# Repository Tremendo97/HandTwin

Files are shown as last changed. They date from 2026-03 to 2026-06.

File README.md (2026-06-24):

Este es el repositorio para el Trabajo Fin de Grado de Diego Hernández Pérez para el grado de de Desarrollo de aplicaciones 3D interactivas y videojuegos.

Resumen:

En el panorama actual se observa una gran explosión en la importancia de los gemelos digitales, siendo utilizados para una gran cantidad de actividades tanto dentro como fuera del ámbito industrial. A su vez, a lo largo de los años, se han ido desarrollando y perfeccionando pinzas y manos mecánicas que resultan muy útiles para actividades relacionadas con automatización, desarrollo de prótesis y otras aplicaciones.
En este proyecto de fin de grado se estudia el paradigma actual de las manos mecánicas, en conjunto con el concepto de gemelos digitales, para después proponer un diseño de una mano mecánica que recrea los movimientos de una mano humana real, controlada a través del uso de un Gemelo Digital desarrollado en Unreal 5.
Este proyecto pretende ser un primer paso hacia el control a distancia de manos mecánicas más complejas a través de la construcción de gemelos digitales que ofrezcan feedback real e instantáneo de su estado y posición.

This is the repository for the Bachelor's Thesis of Diego Hernández Pérez for the degree in Interactive 3D Application Development and Video Games.

Abstract:

In the current landscape, there is a significant surge in the importance of digital twins, which are being used for a wide range of applications both within and outside the industrial sector. At the same time, over the years, robotic grippers and mechanical hands have been continuously developed and refined, proving highly useful for tasks related to automation, prosthetics development, and other applications.
This Bachelor's Thesis studies the current state of mechanical hands in conjunction with the concept of digital twins. To then proposes the design of a mechanical hand capable of replicating the movements of a real human hand, controlled through the use of a Digital Twin developed in Unreal Engine 5.
This project aims to serve as a first step toward the remote control of more complex mechanical hands through the development of digital twins that provide real-time and accurate feedback on their state and position.

**Memoria**
[DiegoHernándezPérez-TFG.pdf](https://github.com/user-attachments/files/29307168/DiegoHernandezPerez-TFG.pdf)

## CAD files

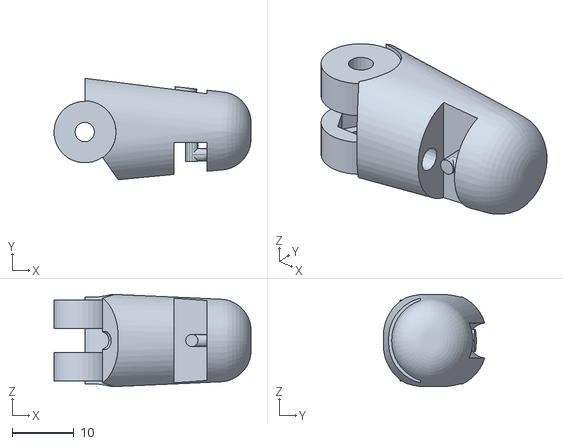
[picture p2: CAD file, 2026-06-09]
stl/anular/falange3_anular_V13.stl
32.0 x 16.5 x 15.0

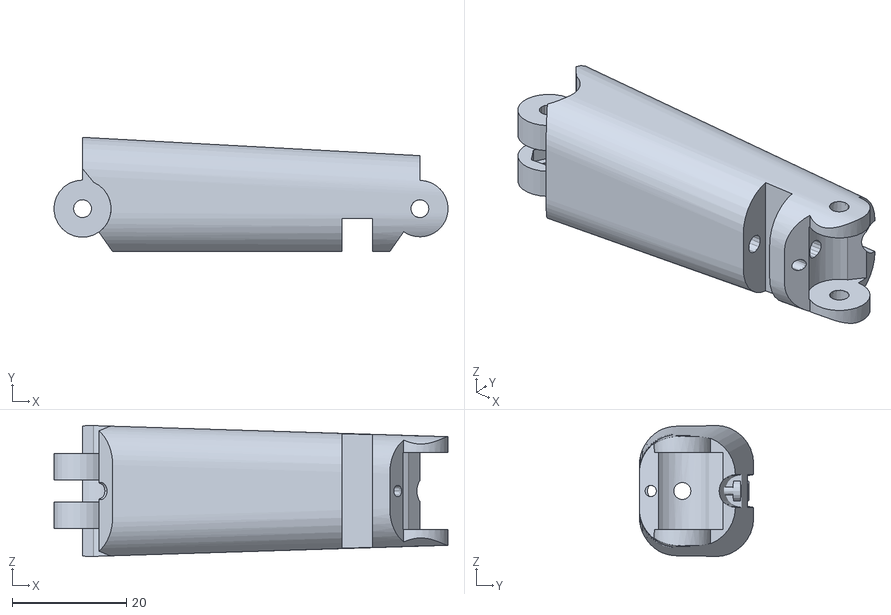
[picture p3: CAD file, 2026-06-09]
stl/corazon/falange1_corazon_V13.stl
68.9 x 20.0 x 22.9

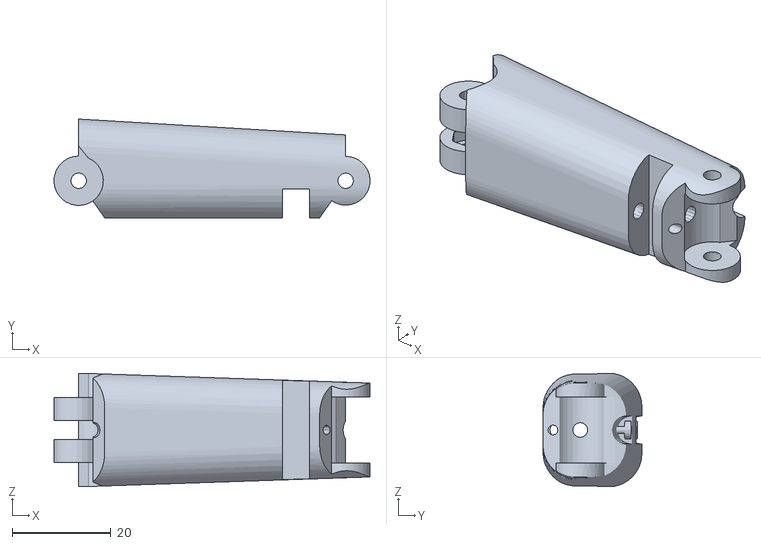
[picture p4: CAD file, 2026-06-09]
stl/indice/falange1_inidice_V13.stl
63.9 x 20.0 x 22.9

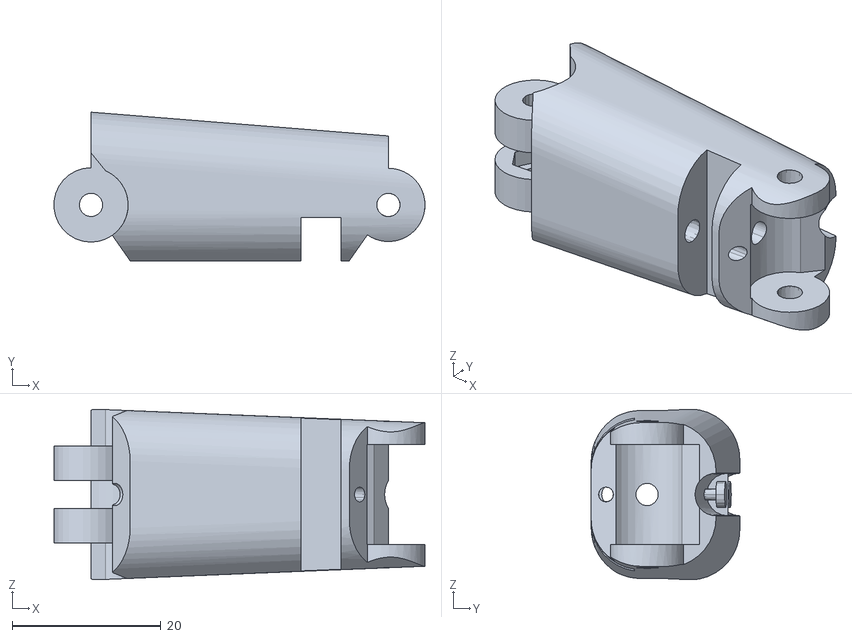
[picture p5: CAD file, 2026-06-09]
stl/menique/falange1_menique_V13.stl
49.9 x 20.0 x 22.9

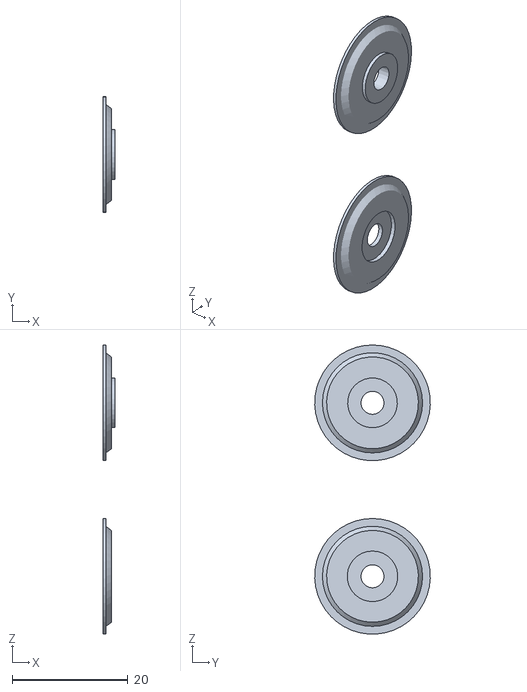
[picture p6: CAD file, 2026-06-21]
stl/poleas/poleas_pulgar_falages23_v13.stl
2.10 x 20.0 x 50.0

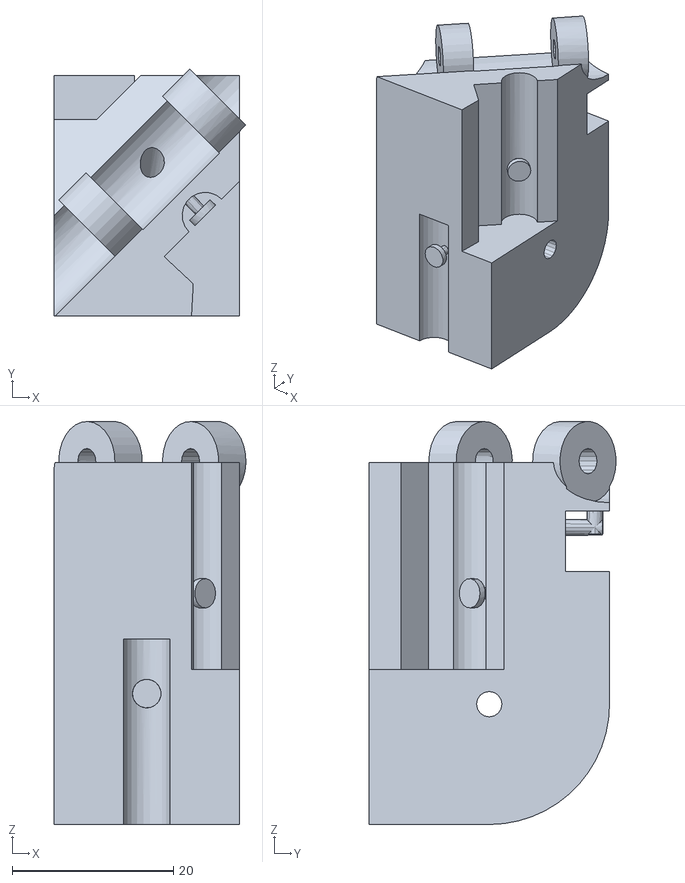
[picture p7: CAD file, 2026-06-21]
stl/pulgar/base_Pulgar_v13.stl
23.8 x 30.7 x 50.0

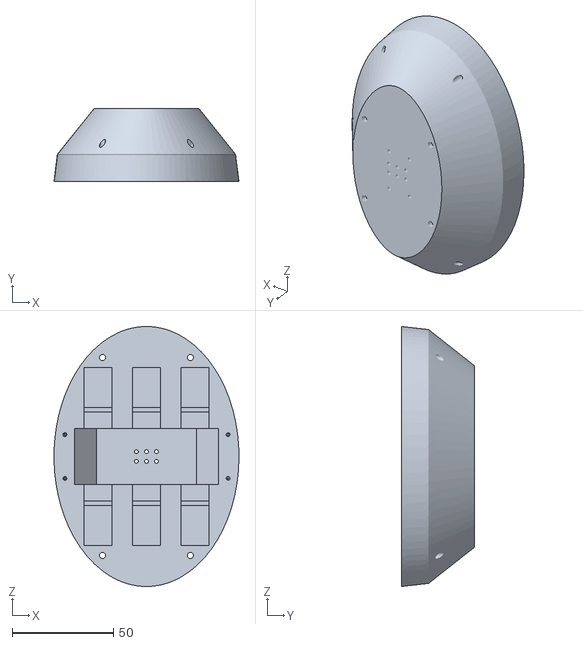
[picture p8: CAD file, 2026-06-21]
stl/tapa_antebrazo_v13.stl
91.4 x 36.0 x 128.5

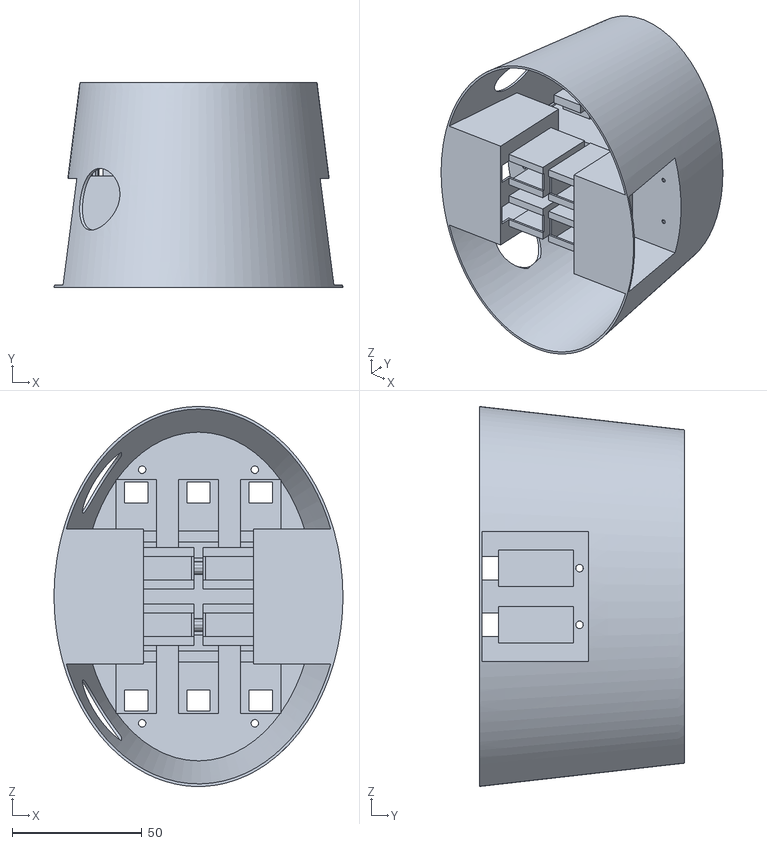
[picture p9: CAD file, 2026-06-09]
stl/antebrazo_v13.stl
111.3 x 78.9 x 146.4

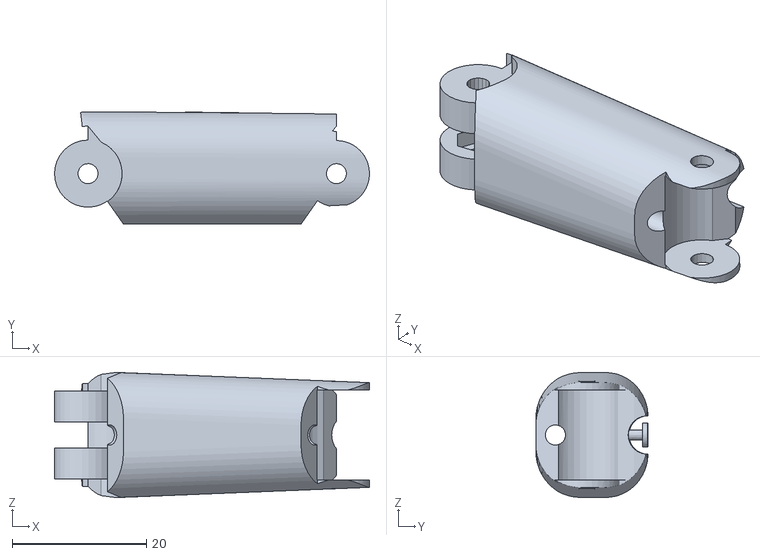
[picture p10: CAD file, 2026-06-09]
stl/anular/falange2_anular_V13.stl
46.9 x 16.7 x 18.6

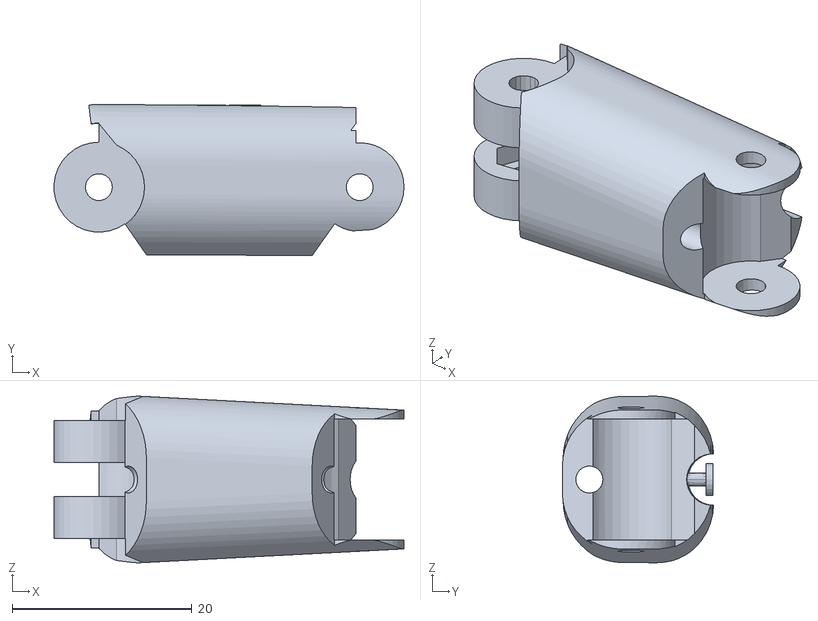
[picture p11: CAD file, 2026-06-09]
stl/indice/falange2_inidice_V13.stl
38.9 x 16.8 x 18.5

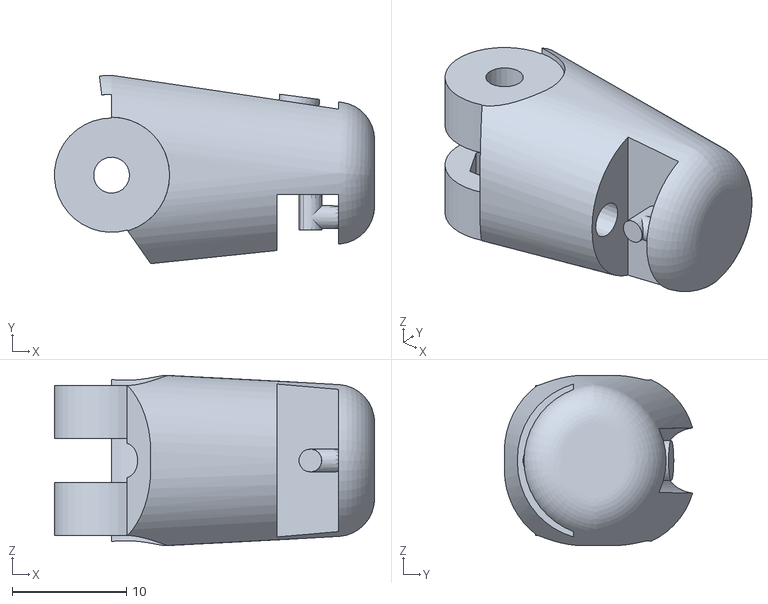
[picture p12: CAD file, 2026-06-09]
stl/menique/falange3_menique_V13.stl
28.0 x 16.5 x 14.9

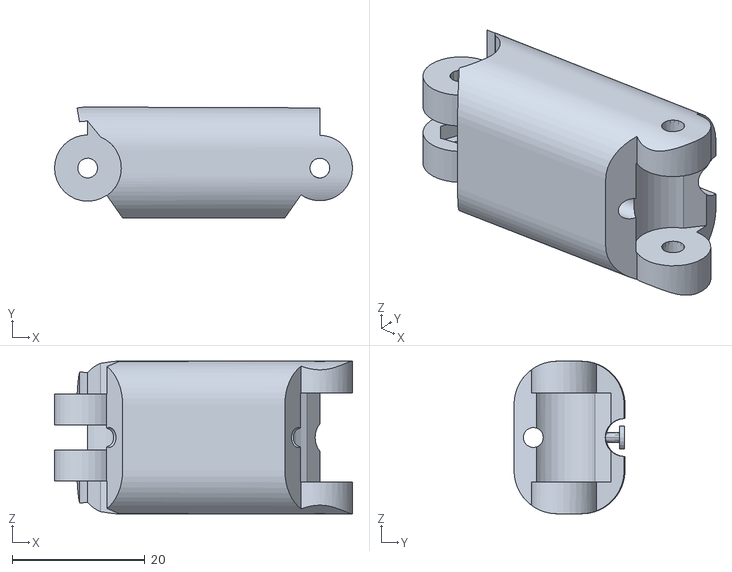
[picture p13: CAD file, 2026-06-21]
stl/pulgar/falange2_Pulgar_v13.stl
44.9 x 16.7 x 23.0

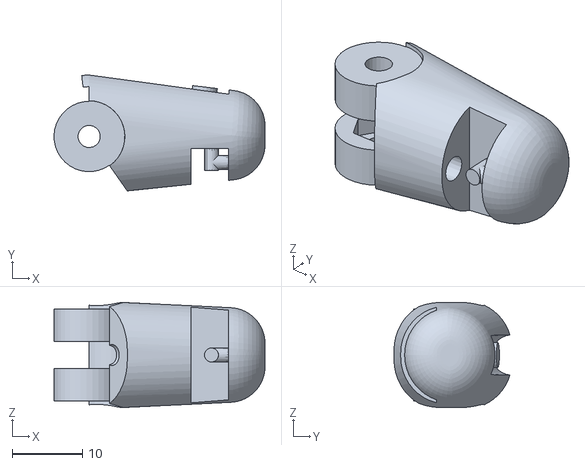
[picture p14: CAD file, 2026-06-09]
stl/indice/falange3_indice_V13.stl
30.0 x 16.5 x 14.9

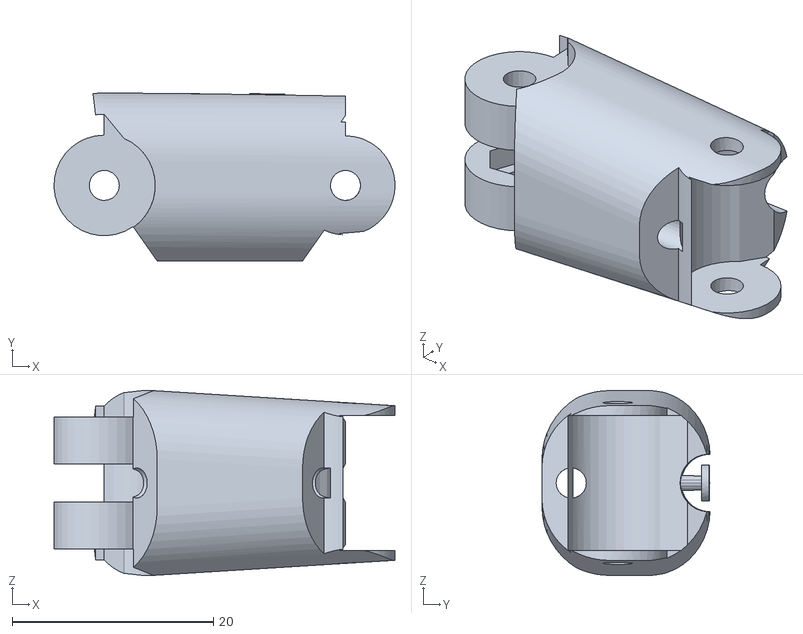
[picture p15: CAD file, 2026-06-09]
stl/menique/falange2_menique_V13.stl
33.9 x 16.7 x 18.4

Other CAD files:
stl/poleas/polea_pulgar_falange1.stl
stl/anular/falange1_anular_V13.stl
stl/corazon/falange3_corazon_V13.stl
ipt/antebrazo_v13.ipt
ipt/anular/falange1_anular_V13.ipt
ipt/anular/falange2_anular_V12ipt.ipt
ipt/anular/falange2_anular_V13.ipt
ipt/anular/falange3_anular_V12.ipt
ipt/anular/falange3_anular_V13.ipt
ipt/corazon/falange1_corazon_V12.ipt
ipt/corazon/falange1_corazon_V13.ipt
ipt/corazon/falange2_corazon_V12ipt.ipt
ipt/corazon/falange2_corazon_V13.ipt
ipt/corazon/falange3_corazon_V12.ipt
ipt/corazon/falange3_corazon_V13.ipt
ipt/indice/falange1_inidice_V12.ipt
ipt/indice/falange1_inidice_V13.ipt
ipt/indice/falange2_inidice_V12ipt.ipt
ipt/indice/falange2_inidice_V13.ipt
ipt/indice/falange3_indice_V12.ipt
ipt/indice/falange3_indice_V13.ipt
ipt/menique/falange1_menique_V12.ipt
ipt/menique/falange1_menique_V13.ipt
ipt/menique/falange2_menique_V12ipt.ipt
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

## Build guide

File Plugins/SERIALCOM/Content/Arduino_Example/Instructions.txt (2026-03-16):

Simple Arduino program:

Arduino:
Analog to Digital:
- Test an analog signal on A0
- Read the sensor value(0-1023)
- Map the sensor range (0-1023) to a range of 1-100
- Print the mapped value to the serial port

Unreal Engine: 

- Copy the BP_Arduino_Comm.uasset inside the "Content" folder of your UE Project.
- Change the "Port" number to the correspondent Port of your Arduino Board.
- Play: The values from 0 to 100 will print on your screen.

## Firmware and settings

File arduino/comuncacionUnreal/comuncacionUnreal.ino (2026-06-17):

#include <Servo.h>

enum Dedo : uint32_t
{
  Indice = 0,
  Corazon = 1,
  Anular = 2,
  Menique = 3,
  Pulgar = 4,
  Vacio = 5
};

struct posicion {
  float pos1;

  float pos2;

  Dedo dedo=Menique;
  
  String toString() {
    return String(dedo) + ": " + String(pos1) + "," + String(pos2);
  }
};

class Hand{
  public:
    Servo indice1;
    Servo indice2;
    Servo corazon1;
    Servo corazon2;
    Servo anular1;
    Servo anular2;
    Servo menique1;
    Servo menique2;
    Servo pulgar1;
    Servo pulgar2;
  public:
    setHand(){
      
      //asignar los servos a sus salidas
      indice1.attach(13);
      indice2.attach(12);

      corazon1.attach(11);
      corazon2.attach(10);

      anular1.attach(9);
      anular2.attach(8);

      menique1.attach(7);
      menique2.attach(6);

      pulgar1.attach(4);
      pulgar2.attach(5);

      //colocar en la posicion por defecto
      corazon1.write(0);
      corazon2.write(0);

      indice1.write(0);
      indice2.write(0);

      anular1.write(0);
      anular2.write(0);

      menique1.write(0);
      menique2.write(0);

      pulgar1.write(0);
      pulgar2.write(0);
    }
  public:
    void setPosition(posicion posiciones){
      switch (posiciones.dedo) {
        case Indice:
          indice1.write(posiciones.pos1);
          indice2.write(posiciones.pos2);
          break;
        case Corazon:
          corazon1.write(posiciones.pos1);
          corazon2.write(posiciones.pos2);
          break;
        case Anular:
          anular1.write(posiciones.pos1);
          anular2.write(posiciones.pos2);
          break;
        case Menique:
          menique1.write(posiciones.pos1);
          menique2.write(posiciones.pos2);
          break;
        case Pulgar:
          pulgar1.write(posiciones.pos1);
          pulgar2.write(posiciones.pos2);
          break;
      }
    }
};

posicion pos;
Hand hand;

void setup() {
  Serial.flush();
  Serial.begin(9600);
  // Serial.begin(115200);
  Serial.setTimeout(1);

  delay(1000);
  
  hand.setHand();
  // Serial.println(sizeof(posicion));
}

void loop() {
  uint8_t buffer[sizeof(pos)];

  // if (Serial.available() >= sizeof(pos)) {
  //   Serial.readBytes((char*)buffer, sizeof(pos));

  //   Serial.write(buffer, sizeof(buffer));

  //   memcpy(&pos, buffer, sizeof(pos));

  //   hand.setPosition(pos);
  // }
  
  if (Serial.available() >= sizeof(pos)) {
    // Leemos los bytes directamente en la estructura
    Serial.readBytes((char*)&pos, sizeof(pos));
    hand.setPosition(pos);
    
  }
  Serial.println(pos.toString());
}

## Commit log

2026-02-25 elimino carpeta de prueba
2026-02-26 Comunicación serial por Arduino mandando estructura para un dedo
2026-03-01 segundas falangalanges y modelos de estas
2026-03-02 prefabs de las teclas colocados
    falta ponerlos en la lista de teclas y sacar las anteriores, además de cambiar las comprobaciones del código a solo prefabs
2026-03-03 controles a traves de teclas
    falta retocar bien pero es funcional la primera falange
2026-03-07 paso de mano a dedos
    Hago este cambio para después poder volver, ya que debo cambiar la clase mano existente por una clase dedo y hacer que herede de ChildActorComponent, para despues hacer un blueprint hand que contenga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
2026-03-16 Cambio entre dedos
    Hay que revisar como se inicializa los de la mano, ahora se hace a traves de la mano en si en el begin play con un switch peor esta regular.
2026-03-22 añado código de Arduino para conectar con Unreal
2026-03-23 cambio materiales y movimientos de camera
    Nuevo material de cell sahding para que se distingan mejor las piezas.
    Zoom de cámara.
    Movimiento hacia delante, detrás y los lados.
2026-03-24 ajustes de ángulos de unreal a arduino
2026-03-30 selección de puertos serie.
    Se añadió una función que identifica a los Arduinos y otros dispositivos en c++, y haciendo usado de esta un menú para poder seleccionarlo.
2026-03-30 pulgar
    nuevas piezas importadas plaga y las que componen el dedo gordo
    Cambio en la dirección en la que cambian los dedos activos
    nuevo BP pulgar que hereda del dedo básico
2026-04-09 Pulgar
    Pulgar bien colocado
    pulgar rota bien
    se tuvo que rotar la geometría de la base del pulgar en blender para que hiciese bien su rotación
    El pulgar no envía la posición al Arduino
2026-04-11 dedo gordo parte de arduino
    el dedo gordo ya recibe datos desde Unreal y se aplican los giros en el arduino
2026-04-14 controles de la cámara
    la cámara ya se puede girar.
    hay inicios de hacer que el usuario pueda cambiar la sensibilidad, velocidad de la cámara y velocidad de los dedos.
2026-04-14 velocidad que se puede cambiar
    la velocidad puede cambiar, tanto desde la UI como con controles
    se ve la sensibilidad y demás por pantalla
    mensaje de error si se trata de poner una velocidad mayor de la posible
2026-04-25 modelos para dedos índice, anular, menique y corazón
    modelos de para los dedos índice, anular, menique y corazón
    blueprints distintos para cada uno que heredan del dedo básico
    arreglo en el widget de error
2026-05-31 nuevos modelos
    Se añadieron modelos de la palma definitiva, antebrazo, la tapa de este y la sujeción de los dedos.
    Estas modificaciones son estéticas para que el aspecto coincida con la palma real.
    También se ajusto la posición de los dedos para que encajasen adecuadamente con la palma.
2026-06-01 bug della tercera falange arreglado
    existia un bug que bloqueaba la tercera falange al subir de nuevo a poca velocidad
    tambien se arreglo el problema de diferencia de velocidad entre la falange 2 y 3 ya que era ocasionado por lo mismo
2026-06-09 UI, pulgar y stl
    Se añade una UI para mostrar por pantalla los mensajes recibidos desde Unreal.
    se cambian los medelos del dedo gordo por sus redondeados
    se elimnan algunos modelos de versiones anteriores que ya no se usan
    se añade una carpeta con los stl de algunas de las piezas finales
    [PalmaSinServos_v13.stl, PalmaSinServos_v13_1.3mf, PalmaSinServos_v13_1.stl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]
2026-06-09 solución de desplazamiento frente a la mano mecanica
    Se añadió un sistema que permite al usuario especificar el punto, de tal manera que el hilo quede tenso siempre.
2026-06-11 guardado de desfases, ajustes en los giros del pulgar
    arreglado el problema del desfase en las primeras falanges
    se han coordinado los servos del pulgar para permitir el movimiento. Antes no era posible debido a un error de diseño en la pieza base del pulgar.
2026-06-12 nuevo icono de ajustar desfases
    se ha añadido un icono para el botón de ajustar el desfase del dedo activo.
2026-06-17 ajustes en versiones de modelos finales
    [base_Pulgar_v13.ipt, falange1_anular_V12.0002.ipt, falange1_anular_V12.ipt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]
2026-06-21 eliminación de gcode y 3mf
    [PalmaSinServos_v13_1.3mf, PalmaSinServos_v13_1_de_pie.3mf, PalmaSinServos_v13_1_de_pie_2.3mf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]
2026-06-21 piezas de anular bien nombradas
    [falange1_anular_V13.ipt, falange2_anular_V13.0001.ipt, falange2_anular_V13.ipt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]
2026-06-21 renombrado corazón
    [falange1_corazon_V12.0002.ipt, falange1_corazon_V12.0003.ipt, falange1_corazon_V13.ipt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]
2026-06-21 índice cambio de nombre
    [falange1_inidice_V13.0001.ipt, falange1_inidice_V13.ipt, falange2_inidice_V13.0003.ipt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]
2026-06-21 cambio de nombres meñique
    [falange1_menique_V13.0003.ipt, falange1_menique_V13.ipt, falange2_menique_V13.0002.ipt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]
2026-06-21 cambios de nombre del pulgar
    [base_Pulgar_v13.0013.ipt, base_Pulgar_v13.ipt, falange2_Pulgar_v13.0008.ipt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]
2026-06-21 todas las piezas y eliminadas las versiones anteriores
    [antebrazo_v13.ipt, base_Pulgar_v13.0013.ipt, falange1_anular_V12.0002.ipt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]
2026-06-21 modelos de stl finales
    [PalmaSinServos_v13.stl, PalmaSinServos_v13_1.stl, Polea_dedoGordo_parte1.stl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]
2026-06-21 textos de licencia de terceros
